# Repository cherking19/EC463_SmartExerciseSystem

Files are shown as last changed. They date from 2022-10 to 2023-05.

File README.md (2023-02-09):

# SeniorDesign_SmartExerciseSystem

Android:
Flutter compileSdkVersion, minSdkVersion, and targetSdkVersion changed to 33

https://stackoverflow.com/questions/72697570/warning-the-plugin-permission-handler-android-requires-android-sdk-version-33
https://pub.dev/packages/flutter_local_notifications#gradle-setup

- All app changes will happen on the smart_gym folder.

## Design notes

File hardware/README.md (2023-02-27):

# Smart Gym Hardware

Circuit Diagram of Arduino Nano 33 BLE, and connected power control circuit and haptic motor controller.

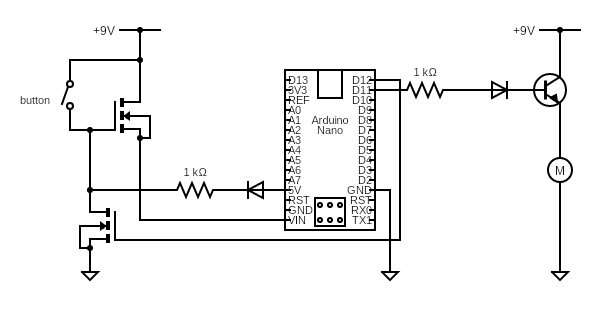
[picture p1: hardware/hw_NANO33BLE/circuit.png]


## Power Control Circuit

The power control circuit is designed to allow the user to power on the device with a single button press. The device will then remain powered on until the arduino sends an "off" signal (High/3.3V) from pin D12. This will cut off current from the connected Voltage Source (In this case, a 9V battery), and power off the arduino. 

The circuit is comprised of two NMOS transistors, a diode, and a resistor. The purpose of the first (top) transistor is to connect the positive terminal of the battery to the Vin pin. The transistor is opened by connecting the gate 9V, allowing the voltage source to pass to Vin. Once the arduino is powered on, the 5V output will turn on, and keep the first transistor open when the button is released. The diode prevents current from flowing back into the arduino when the button and 5V pins are both active. The second transistor will be off while the arduino is active, preventing any current flow from the 5V output, except for leakage. When the software determines that the arduino is inactive and will shut down, the second transistor is opened by setting D12 to HIGH. This pulls the gate of the first transistor to 0V, which turns off the transistor, and cuts off power to the arduino. Some current will pass through the resistor via the 5V pin very briefly.

This method powers on/off the device as soon as the button is pressed / the HIGh signal is sent to the second transistor.

## Haptic Motor
The Haptic Motor is controlled by a simple BJT transitor, modulated by pin D11, connected through a resistor and a diode to the BJT's gate. This allows current to flow from the 9V source through the motor when D11 is set to HIGH. In software, D11 can be set to HIGH for brief moments to activate the vibrate function. 

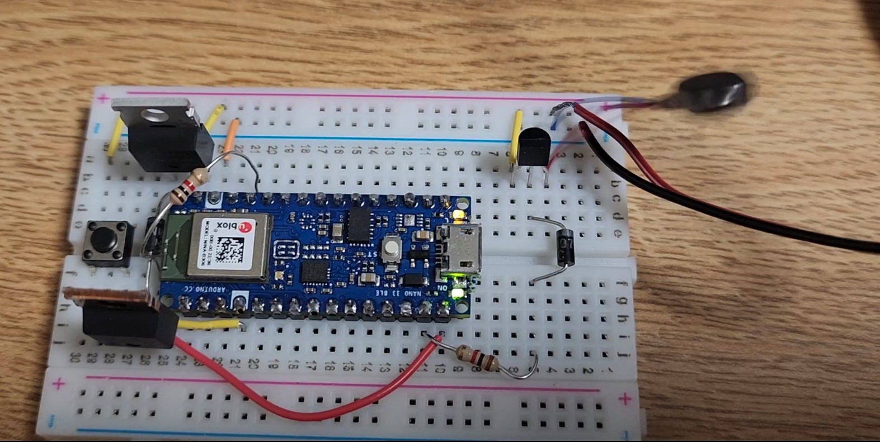
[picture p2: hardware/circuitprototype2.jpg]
prototype

(Prototype)

Arduino code:
In addition to library manager libraries: https://github.com/FemmeVerbeek/Arduino_LSM9DS1
library manager libraries: Adafruit_AHRS, ArduinoBLE

NOTE: In order to use the 5V pin, you must solder the VUSB pad

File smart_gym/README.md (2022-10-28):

# smart_gym

A new Flutter project.

## Getting Started

This project is a starting point for a Flutter application.

A few resources to get you started if this is your first Flutter project:

- [Lab: Write your first Flutter app](https://docs.flutter.dev/get-started/codelab)
- [Cookbook: Useful Flutter samples](https://docs.flutter.dev/cookbook)

For help getting started with Flutter development, view the
[online documentation](https://docs.flutter.dev/), which offers tutorials,
samples, guidance on mobile development, and a full API reference.

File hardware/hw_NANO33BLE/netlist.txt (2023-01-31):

* Netlist created with www.circuit-diagram.org
* seniordesignpower
D1 0 1
V2 2 0
'motor b:2 a:3 t=Generic
V3 4 9
'transnpn emit:1 base:3 col:4 t=NPN
R4 5 0 1000
V5 6 0
'toggleswitch a:7 t=Toggle closed=False
'Arduino Nano 28:5 18:6 14:8 29:9 11:10
'Arduino Nano
D6 10 11
V7 12 0
V8 7 9
R9 7 11 1000
'mosfetn gate:8 drn:7 t=NChannelMosfet
'mosfetn drn:7 gate:12 t=NChannelMosfet

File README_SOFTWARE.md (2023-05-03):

## Software

### Modules

The UI consists of pages for creating, managing, and tracking workout routines. The main page is made up of 3 tabs: Workout, History, and Settings.

#### Workout

The Workout tab is where the user creates routines and tracks workouts. In the paradigm of the app, a routine/workout contains the:

- Workout name
- A list of exercises that make up the workout

An exercise contains the:
- Exercise name
- A list of sets that make up the exercise
- Flags that indicate whether the sets share repetition, weight, and rest information

A set contains the: 
- Number of repetitions
- Weight 
- Rest duration

The Create Workout page consists of a form where the user enters information to create a routine. Upon the form initialization, a routine object is created to represent the workout. Each widget of the form corresponds to an element in the routine object according to the paradigm above. For example, modifications to an exercise widget will directly modify the values within the corresponding exercise. The form also validates the input to ensure each workout is named, contains at least one exercise, and has valid set information for each exercise. 

A user’s workout routines are saved in an unordered map for efficient retrieval. Each routine has an associated UUID to act as the key. This UUID is not visible to the user but allows multiple routines of the same name. 

The View Workouts page will display all the routines that the user has created. Upon initialization, this map is loaded and a list item generated from each entry. Clicking on one will display that routine’s information. Here, the user can edit the routine in a manner similar to the workout creation or delete the routine entirely. They can also begin tracking the workout, which will open the Track Workout page. 

When the workout is beginning to be tracked, its information is passed to the Track Workout service. This ensures that the information is both accessible throughout the app and also persists even when the Track Workout page is no longer displayed. These functionalities are required because the user will interact with the tracked workout in two ways: primarily through the Track Workout page where the complete workout progress is displayed and recorded but also through the Rest Timer widget which appears at the bottom of the Workout Page to indicate the current rest time. Multiple timer services are also running in the background to keep track of the rest duration and elapsed workout duration. 
Within the Track Workout page, the user will execute the workout. The user can either manually or automatically track each set of an exercise. In manual tracking, the user will perform the set without the analysis of the sensors and record how many successful repetitions they completed by tapping on the rep counter. 

The automatic tracking interfaces with the sensor service which provides the most up to date sensor measurements. These measurements are organized in a map, where the key is the name of the sensor node corresponding to the position on the body, and the value is the most recent measurement at that node. Each time new measurements are received, the service will update the map and broadcast an event. The track workout service contains a listener that will listen for these events and will subsequently run an iteration of the exercise analysis. By examining the change in sensor measurements from one iteration to the next, the analysis can determine whether a rep has been successfully completed, and report to the UI to reflect progress.

#### History

The History module displays the results of recorded workouts in both a List and Calendar view. Clicking on a record will enter the View Completed Workout page, where the user can view their results for that workout. While a workout object can represent a template of a routine, it can also represent a completed workout’s results. There are additional nullable fields for maintaining the start date and time and workout duration. Set objects also contain an additional reps completed value. This allows progress to be directly recorded into the same template that is loaded into a Track Workout page and saved in the same format. As a result, the UI for viewing a completed workout can be very similar and functionality can be borrowed when making edits to a completed workout. The completed workouts are themselves saved in a manner very similar to a user’s workout templates. 

#### Settings

Within the Settings module, the user can edit their profile and connect to the Smart Gym sensors. The Bluetooth settings page will display all the Smart Gym sensors in range that are connectable, as well as those that are already connected. This system makes use of the FlutterBlue plugin which takes care of many of the lower level Bluetooth system calls to enable cross platform Bluetooth functionality. Upon opening the Bluetooth settings page, the app periodically listens for newly connected and scanned Bluetooth devices. These results are filtered so that only devices with a preset device name prefix are displayed, ensuring that within the app the user can only interact with Smart Gym sensors. When a device is connected, the app begins listening to the orientation service as named in the Arduino code, and continuously retrieves the measurement data. This data is then passed to the previously mentioned sensor service and made available to the entirety of the app. 

### Software Flowchart

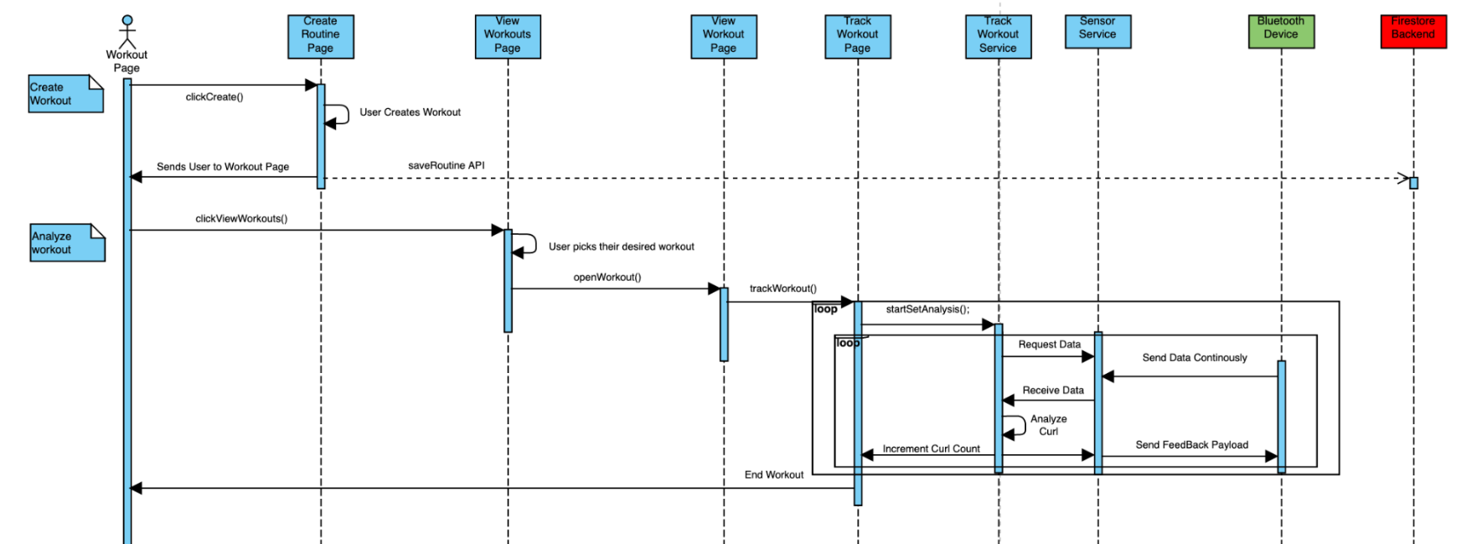
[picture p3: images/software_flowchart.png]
Flowchart


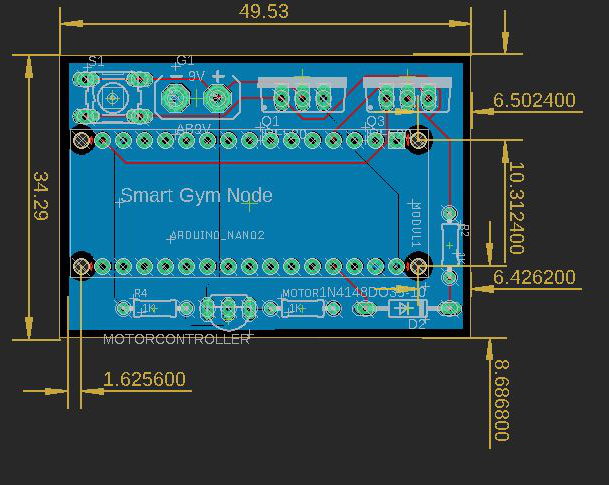
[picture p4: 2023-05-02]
hardware/pcb.jpg

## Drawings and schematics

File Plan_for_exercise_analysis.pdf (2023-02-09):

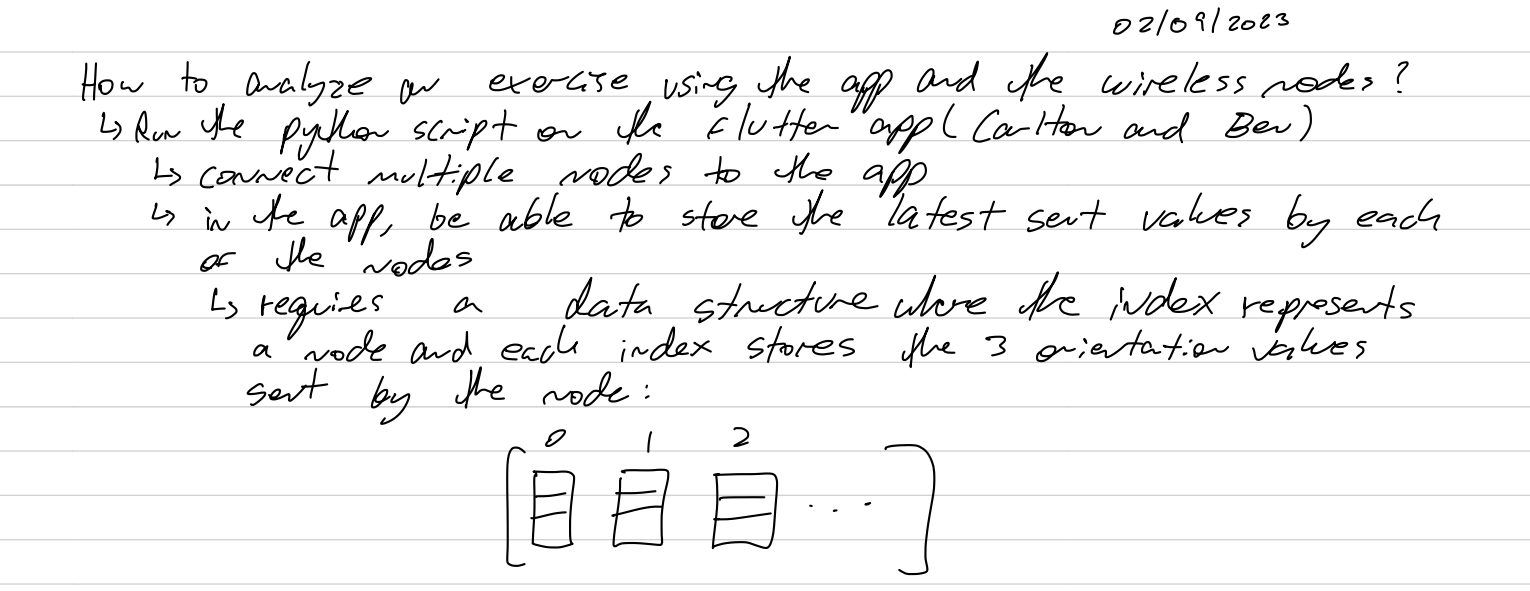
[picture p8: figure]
↳ correctmultiple rodes totheapp; ofthe rodes; setby the mode: LEEE...]

How to analyze or | exercise | using theapp and the wireless modes?
↳ Row thepython scriptor the flutter apple Coulton and Berl
2 | in theapp, be able tostorethelatestsentvalues by each
↳s requires | data structure where the index represents a | rode andeach index stores | the orientation values
Pebate between Coulter and Bor abouthow we | should approach
Ber: we | should label each ofthe rodes and tell the uses which

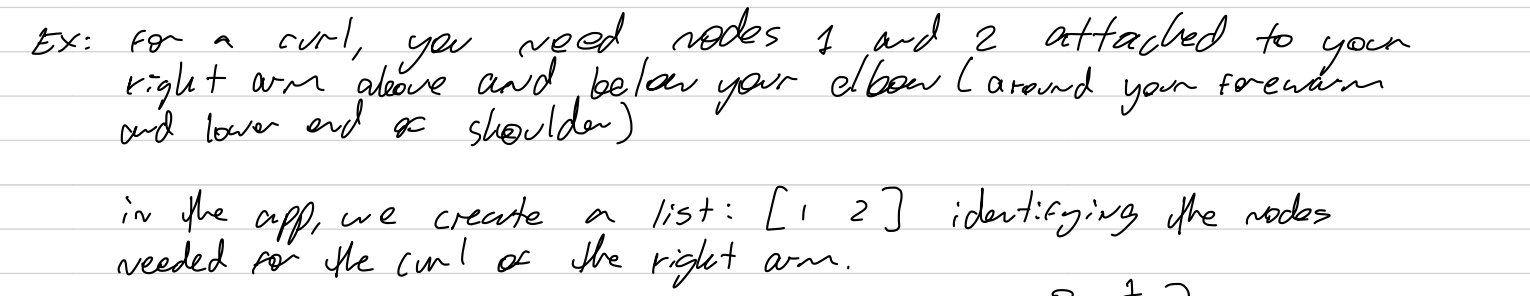
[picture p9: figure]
forewarm; and lower and ofshoulder); in theapp, we; createa list:[12] identifying the rodes; needed to the curl oftherightarm.

Ex.for | a | surl, you need nodes 1 | and I | attached toyour rightare above and below your allow (around your

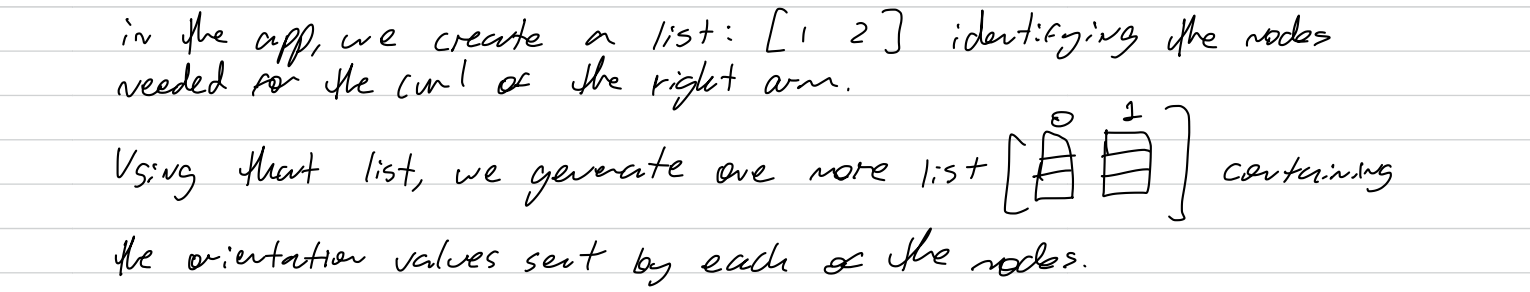
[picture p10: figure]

Using thatlist, we | generate aremore | listcertaining

the orientation values sentby each ofthemodes.

Then, we | send thisfinal listto thescriptfor theanalysis ofthe
Carlton:We | should have all the rodes as genetic and the app assigns
a | label toeach of the rodes dynamically. Theuse knows

to your rightforearm. Now, attach vileating rode (the Nextore) tothe

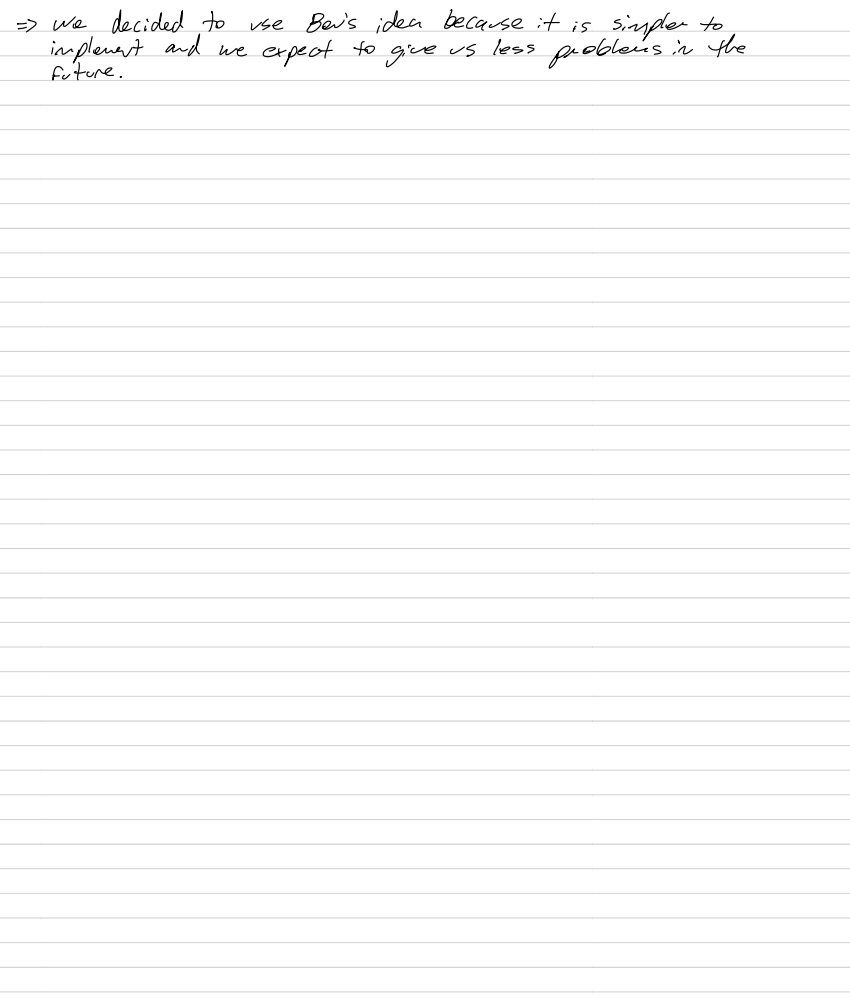
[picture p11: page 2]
decided to; use; Bar's idea because itis simpler to; implementand we; expecttogive as; less problems in the; future.

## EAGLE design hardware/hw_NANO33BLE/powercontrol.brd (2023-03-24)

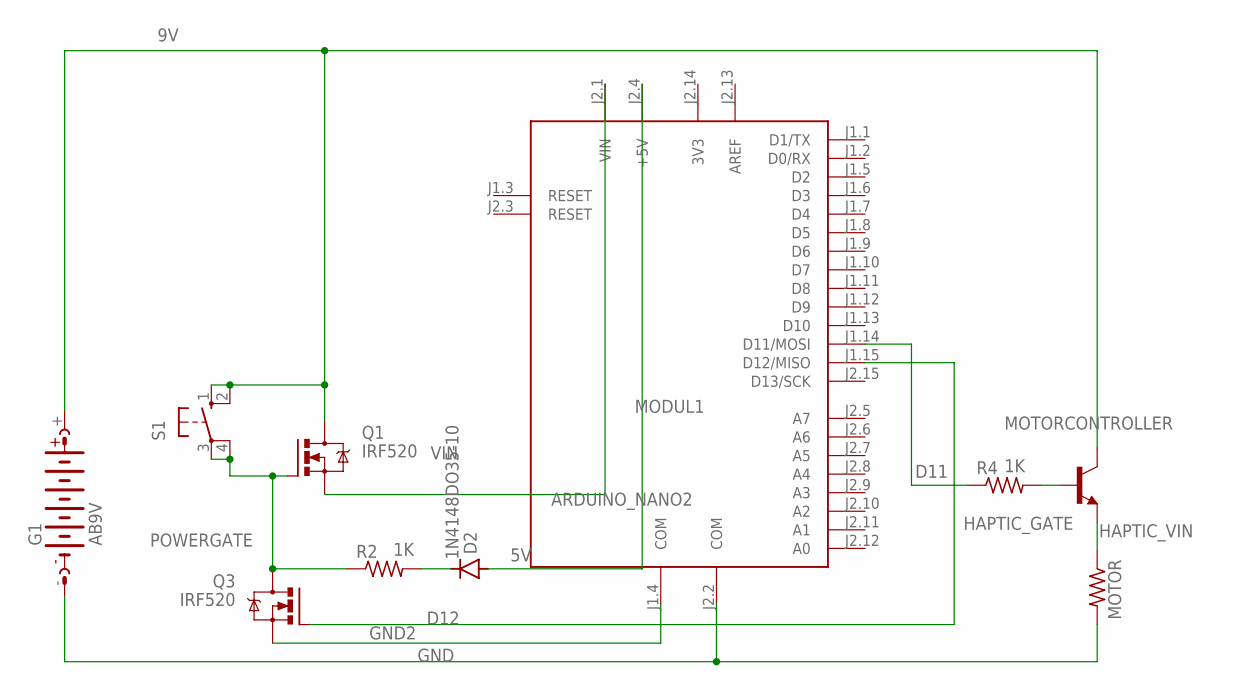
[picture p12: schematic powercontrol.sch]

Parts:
D2: 1N4148DO35-10; DO35-10
G1: AB9V
MODUL1: ARDUINO_NANO2
MOTOR: 1K; 0204/7
MOTORCONTROLLER: 2N2222-NPN-TO92-EBC; TO92-EBC
Q1, Q3: IRF520; TO220BV
R2, R4: 1K; 0204/7
S1: 10-XX; B3F-10XX

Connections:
3V3: MODUL1.J2.14 (3V3)
5V: D2.A, MODUL1.J2.4 (+5V)
9V: G1.+, MOTORCONTROLLER.C, Q1.D, S1.1 (S), S1.2 (S1)
AREF: MODUL1.J2.13 (AREF)
D11: MODUL1.J1.14 (D11/MOSI), R4.1
D12: MODUL1.J1.15 (D12/MISO), Q3.G
DIODE_TO_RESISTOR: D2.C, R2.2
GND: G1.-, MODUL1.J2.2 (COM), MOTOR.2
GND2: MODUL1.J1.4 (COM), Q3.S
HAPTIC_GATE: MOTORCONTROLLER.B, R4.2
HAPTIC_VIN: MOTOR.1, MOTORCONTROLLER.E
POWERGATE: Q1.G, Q3.D, R2.1, S1.3, S1.4 (P1)
VIN: MODUL1.J2.1 (VIN), Q1.S

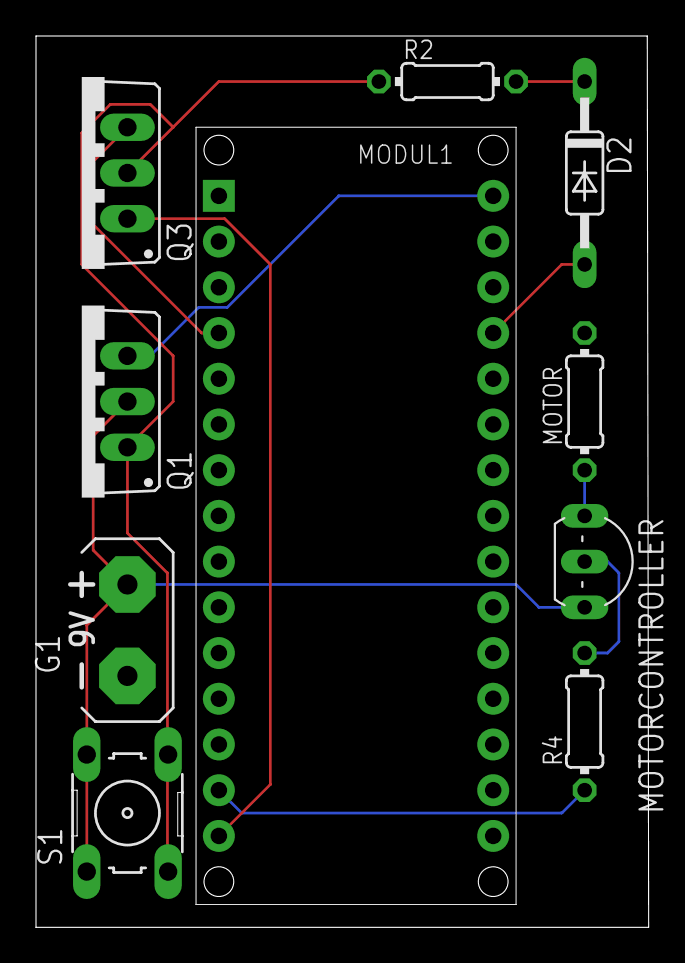
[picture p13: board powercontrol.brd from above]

Board: 2 copper layers, 34.0 x 49.5 mm, 10 parts (0 on the bottom side), 11 nets.

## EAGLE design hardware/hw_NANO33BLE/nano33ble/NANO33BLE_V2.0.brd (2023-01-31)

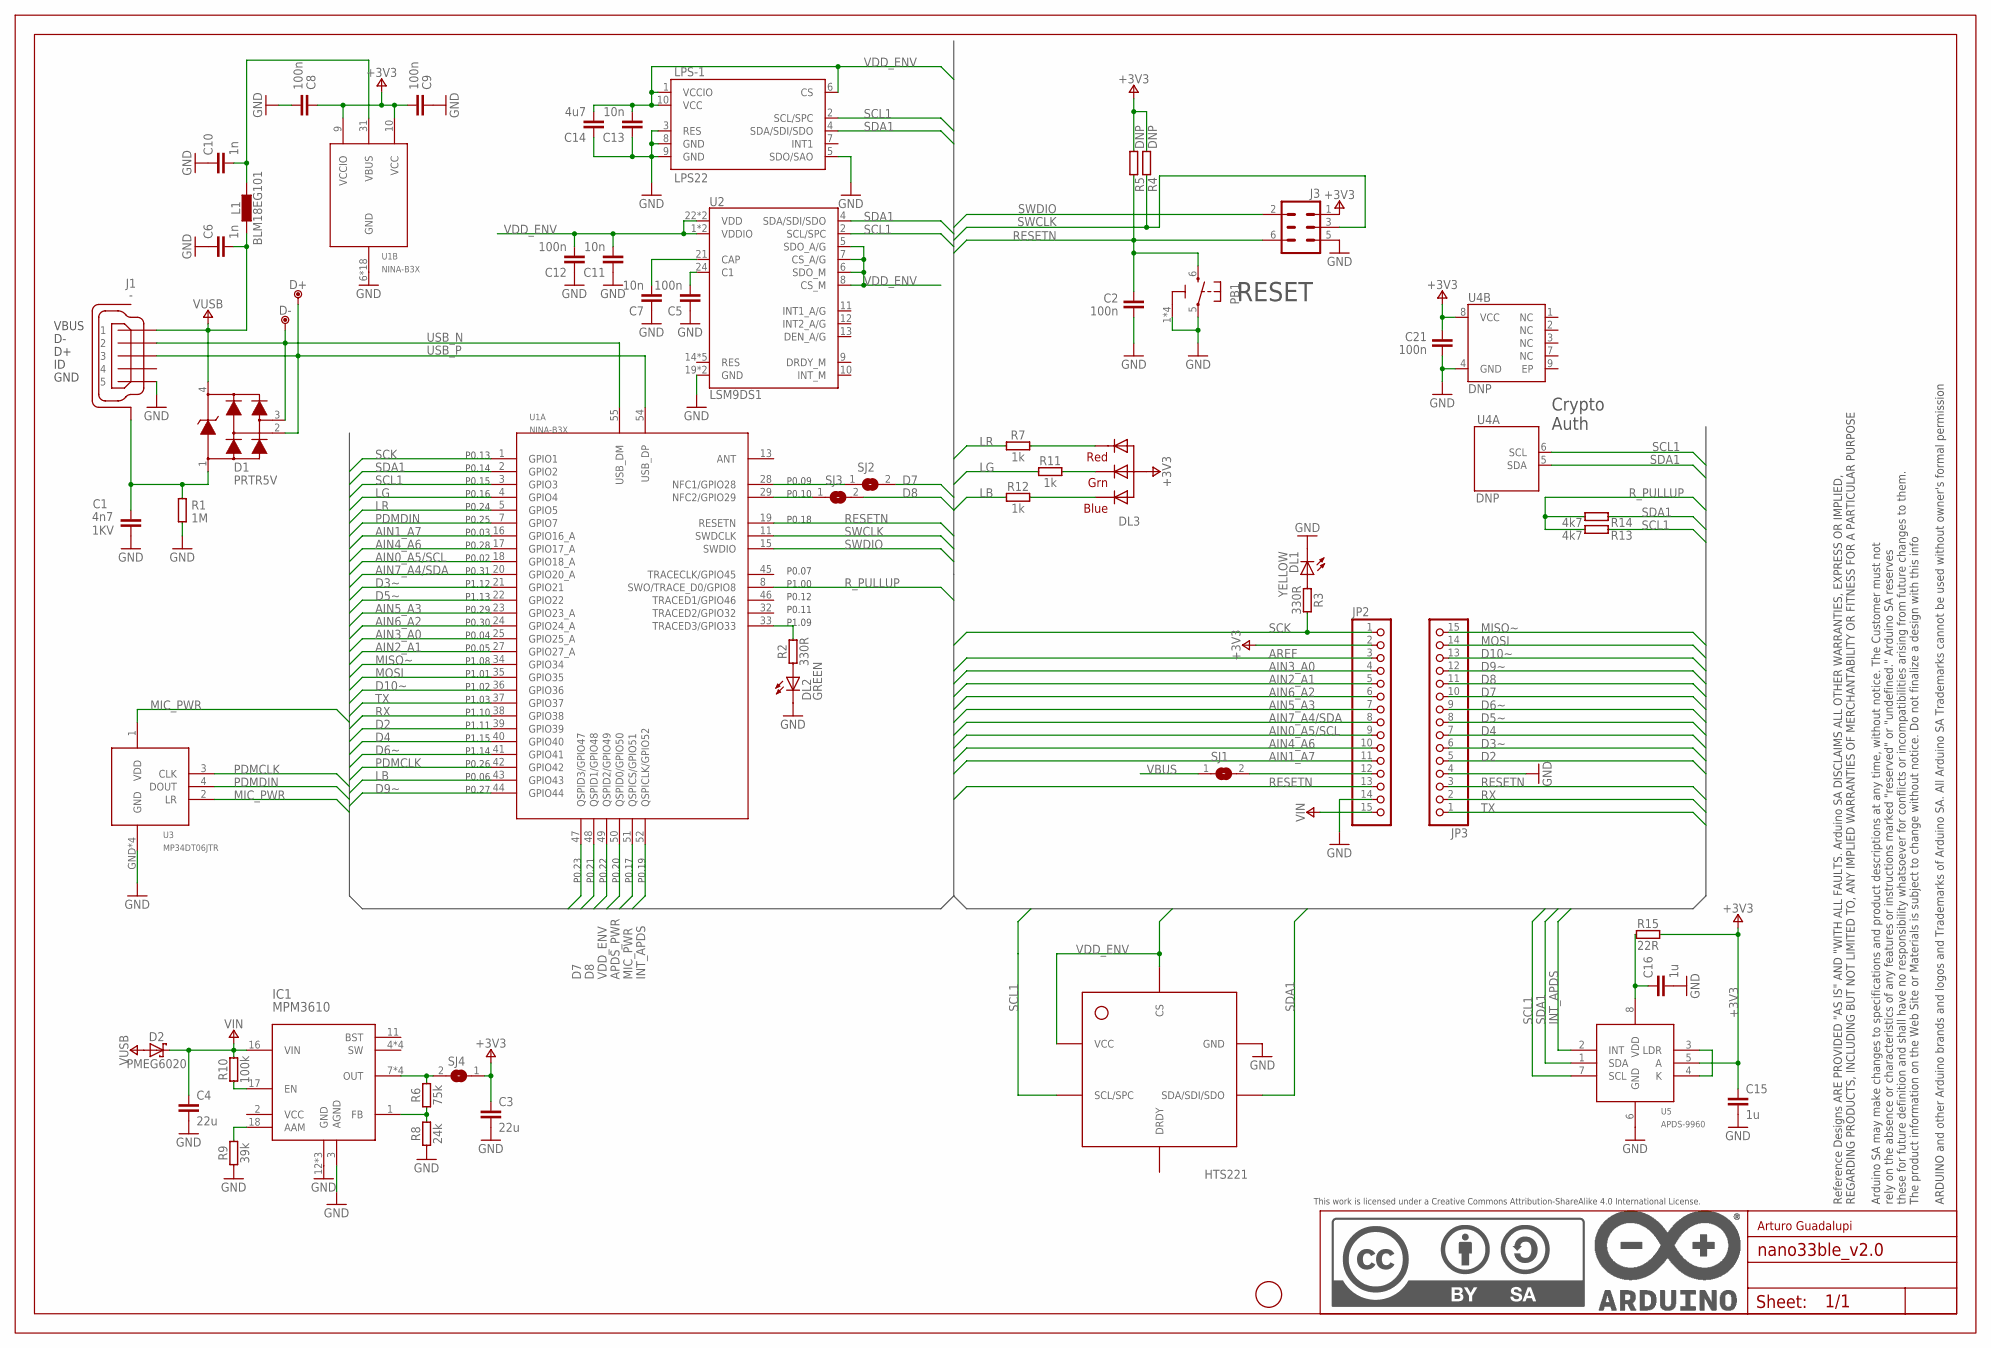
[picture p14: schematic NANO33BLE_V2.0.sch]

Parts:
C1: 4n7; 0805-R2013X50N; VOLTAGE 1KV
C2, C5, C8, C9, C12, C21: 100n; 0402-1005X55N
C3, C4: 22u; 0805-R2013X50N
C6, C10: 1n; 0402-1005X55N
C7, C11, C13: 10n; 0402-1005X55N
C14: 4u7; 0402-1005X55N
C15, C16: 1u; 0402-1005X55N
D1: PRTR5V; SOT190P230X110-4N
D2: PMEG6020; SODFL3517X110N
D+: DNP; TP-1.00MM
D-: DNP; TP-1.00MM
DL1: YELLOW; LEDC1608X80N-AK
DL2: GREEN; LEDC1608X80N-AK
DL3: -; SMLP34RGB2W
FD1: DNP; FD-1-1.5
FRAME1: DNP; FRAME
HS-1: HTS221
IC1: MPM3610
J1: -; ZX62-AB-5PA
J3: DNP; 2X03-TP1
JP2, JP3: PINHD-1X15-CASTELLATED; 1X15-CASTELL
L1: BLM18EG101; 0603-1608X90N
LPS-1: LPS22; LPS22H
PB1: PTS820; C&K_PTS820_NO_HOLES
R1: 1M; 0402-1005X55N
R2, R3: 330R; 0402-1005X55N
R4, R5: DNP; 0402-1005X55N
R6: 75k; 0402-1005X55N
R7, R11, R12: 1k; 0402-1005X55N
R8: 24k; 0402-1005X55N
R9: 39k; 0402-1005X55N
R10: 100k; 0402-1005X55N
R13, R14: 4k7; 0402-1005X55N
R15: 22R; 0402-1005X55N
SJ1, SJ2, SJ3, SJ4: DNP; SJ
U1: NINA-B3X
U2: LSM9DS1; LSM9DS1_TEMP_LGA24-8X4
U3: MP34DT06JTR; HCLGA
U4: DNP; SON50P300X200X60-9N-EP160X140
U5: APDS-9960; APDS9960

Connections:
+3V3: C3.1, C8.1, C9.2, C15.1, C21.1, DL3.1 (A), J3.1, JP2.2, R4.2, R5.2, R15.2, SJ4.1, U1.9 (VCCIO), U1.10 (VCC), U4.8 (VCC), U5.5 (A)
AIN0_A5/SCL: JP2.9, U1.18 (GPIO18_A)
AIN1_A7: JP2.11, U1.16 (GPIO16_A)
AIN2_A1: JP2.5, U1.27 (GPIO27_A)
AIN3_A0: JP2.4, U1.25 (GPIO25_A)
AIN4_A6: JP2.10, U1.17 (GPIO17_A)
AIN5_A3: JP2.7, U1.23 (GPIO23_A)
AIN6_A2: JP2.6, U1.24 (GPIO24_A)
AIN7_A4/SDA: JP2.8, U1.20 (GPIO20_A)
APDS_PWR: U1.50 (QSPID0/GPIO50)
AREF: JP2.3
D2: JP3.5, U1.39 (GPIO39)
D3~: JP3.6, U1.21 (GPIO21)
D4: JP3.7, U1.40 (GPIO40)
D5~: JP3.8, U1.22 (GPIO22)
D6~: JP3.9, U1.41 (GPIO41)
D7: JP3.10, SJ2.2, U1.47 (QSPID3/GPIO47)
D8: JP3.11, SJ3.2, U1.48 (QSPID1/GPIO48)
D9~: JP3.12, U1.44 (GPIO44)
D10~: JP3.13, U1.36 (GPIO36)
GND: C1.2, C2.2, C3.2, C4.2, C5.1, C6.1, C7.1, C8.2, C9.1, C10.1, C11.1, C12.1, C13.1, C14.1, C15.2, C16.2, C21.2, DL1.C, DL2.C, HS-1.P$5.GND (GND), IC1.3 (AGND), IC1.12 (GND), IC1.13 (GND), IC1.14 (GND), J1.5, J3.5, JP2.14, JP3.4, LPS-1.3 (RES), LPS-1.5 (SDO/SAO), LPS-1.8 (GND), LPS-1.9 (GND), PB1.1 (3), PB1.2 (3), PB1.3, PB1.4 (3), PB1.5 (1), R1.1, R8.1, R9.1, U1.6 (GND), U1.12 (GND), U1.14 (GND), U1.26 (GND), U1.30 (GND), U1.53 (GND), U1.GND@1 (GND), U1.GND@2 (GND), U1.GND@3 (GND), U1.GND@4 (GND), U1.GND@5 (GND), U1.GND@6 (GND), U1.GND@7 (GND), U1.GND@8 (GND), U1.GND@9 (GND), U1.GND@10 (GND), U1.GND@11 (GND), U1.GND@12 (GND), U2.19 (GND), U2.20 (GND), U3.GND, U3.GND@2 (GND), U3.GND@3 (GND), U3.GND@4 (GND), U4.4 (GND), U5.6 (GND)
INT_APDS: U1.52 (QSPICLK/GPIO52), U5.2 (INT)
LB: R12.1, U1.43 (GPIO43)
LG: R11.1, U1.4 (GPIO4)
LR: R7.1, U1.5 (GPIO5)
MIC_PWR: U1.51 (QSPICS/GPIO51), U3.1 (VDD), U3.2 (LR)
MISO~: JP3.15, U1.34 (GPIO34)
MOSI: JP3.14, U1.35 (GPIO35)
unnamed: C1.1, D1.1, J1.6 (SH), J1.7 (SH), J1.8 (SH), J1.9 (SH), J1.10 (SH), J1.11 (SH), R1.2
unnamed: DL2.A, R2.1
unnamed: DL1.A, R3.1
unnamed: C5.2, U2.24 (C1)
unnamed: IC1.1 (FB), R6.1, R8.2
unnamed: IC1.18 (AAM), R9.2
unnamed: IC1.17 (EN), R10.1
unnamed: C7.2, U2.21 (CAP)
unnamed: U5.3 (LDR), U5.4 (K)
unnamed: R2.2, U1.33 (TRACED3/GPIO33)
unnamed: DL3.3 (BLUE_C), R12.2
unnamed: DL3.2 (RED_C), R7.2
unnamed: DL3.4 (GREEN_C), R11.2
unnamed: JP2.12, SJ1.2
unnamed: C16.1, R15.1, U5.8 (VDD)
unnamed: IC1.7 (OUT), IC1.8 (OUT), IC1.9 (OUT), IC1.20 (OUT), R6.2, SJ4.2
NFC1: SJ2.1, U1.28 (NFC1/GPIO28)
NFC2: SJ3.1, U1.29 (NFC2/GPIO29)
PDMCLK: U1.42 (GPIO42), U3.3 (CLK)
PDMDIN: U1.7 (GPIO7), U3.4 (DOUT)
RESETN: C2.1, J3.6, JP2.13, JP3.3, PB1.6 (2), R5.1, U1.19 (RESETN)
RX: JP3.2, U1.38 (GPIO38)
R_PULLUP: R13.2, R14.2, U1.8 (SWO/TRACE_D0/GPIO8)
SCK: JP2.1, R3.2, U1.1 (GPIO1)
SCL1: HS-1.P$2.SCL/SPC (SCL/SPC), LPS-1.2 (SCL/SPC), R13.1, U1.3 (GPIO3), U2.2 (SCL/SPC), U4.6 (SCL), U5.7 (SCL)
SDA1: HS-1.P$4.SDA/SDI/SDO (SDA/SDI/SDO), LPS-1.4 (SDA/SDI/SDO), R14.1, U1.2 (GPIO2), U2.4 (SDA/SDI/SDO), U4.5 (SDA), U5.1 (SDA)
SWCLK: J3.3, R4.1, U1.11 (SWDCLK)
SWDIO: J3.2, U1.15 (SWDIO)
TX: JP3.1, U1.37 (GPIO37)
USB_N: D1.3, D-.X, J1.2, U1.55 (USB_DM)
USB_P: D1.2, D+.X, J1.3, U1.54 (USB_DP)
VBUS: C10.2, L1.2, SJ1.1, U1.31 (VBUS)
VDD_ENV: C11.2, C12.2, C13.2, C14.2, HS-1.P$1.VDD (VCC), HS-1.P$6.CS (CS), LPS-1.1 (VCCIO), LPS-1.6 (CS), LPS-1.10 (VCC), U1.49 (QSPID2/GPIO49), U2.1 (VDDIO), U2.3 (VDDIO), U2.5 (SDO_A/G), U2.6 (SDO_M), U2.7 (CS_A/G), U2.8 (CS_M), U2.22 (VDD), U2.23 (VDD)
VIN: C4.1, D2.C, IC1.16 (VIN), JP2.15, R10.2
VUSB: C6.2, D1.4, D2.A, J1.1, L1.1

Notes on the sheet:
RESET
Crypto Auth
Arturo Guadalupi
HTS221

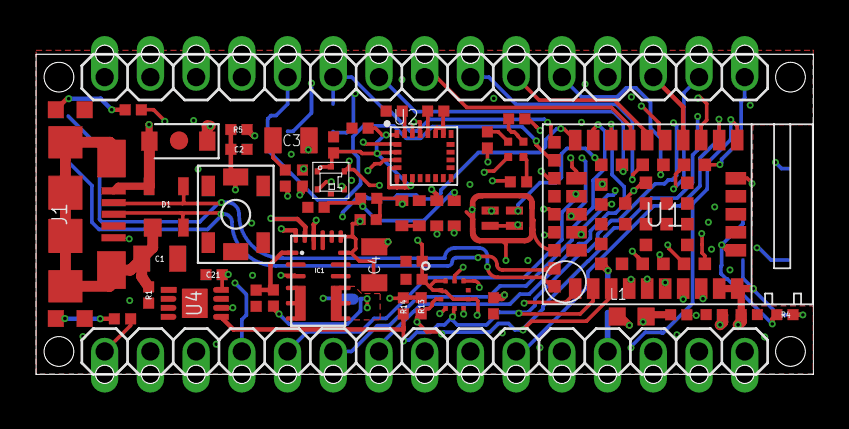
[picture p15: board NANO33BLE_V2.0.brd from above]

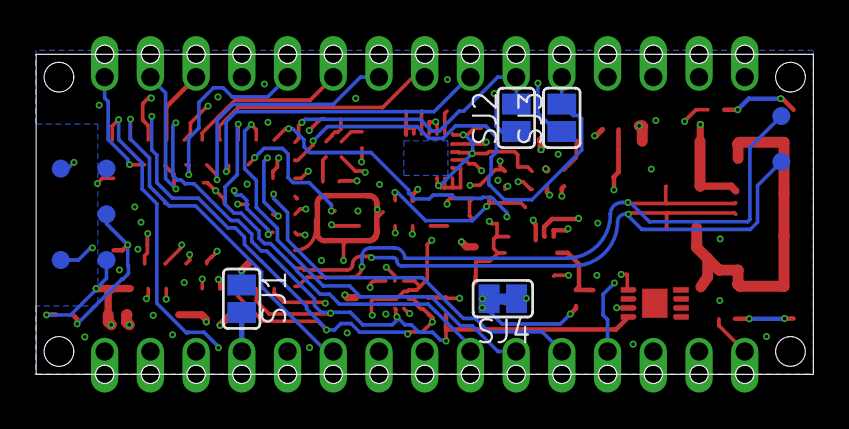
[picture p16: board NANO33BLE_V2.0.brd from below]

Board: 4 copper layers, 43.2 x 17.8 mm, 59 parts (4 on the bottom side), 61 nets.

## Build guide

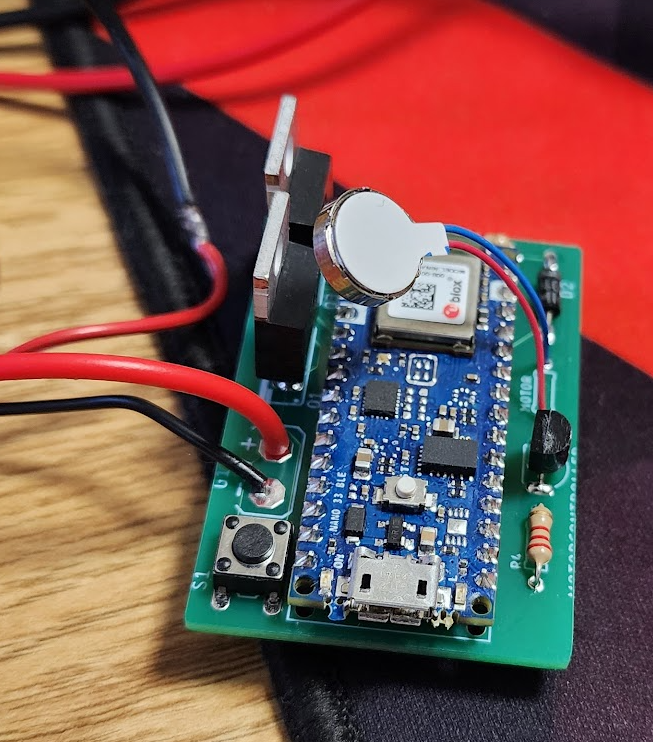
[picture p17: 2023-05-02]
hardware/pcb_assembled.png

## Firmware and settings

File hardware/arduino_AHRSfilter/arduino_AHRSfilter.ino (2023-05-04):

#include <Arduino_LSM9DS1.h>
#include <Adafruit_AHRS.h>
#include <ArduinoBLE.h>
#define sensorRate 104.00
Adafruit_Mahony filter;

BLEService AHRSfilter("A123");                                              // create service
BLEFloatCharacteristic RollCharacteristic("2A19", BLERead | BLENotify);     //create Characteristic
BLEFloatCharacteristic PitchCharacteristic("2A20", BLERead | BLENotify);    //create Characteristic
BLEFloatCharacteristic HeadingCharacteristic("2A21", BLERead | BLENotify);  //create Characteristic

BLEService HapticFeedback("A124");
BLEByteCharacteristic switchCharacteristic("2A57", BLERead | BLEWrite);

//PINS
#define powerdrain 12
#define haptic 11

unsigned long start_time;
unsigned long last_connected_time;
unsigned long hapticTime;
char* deviceName = "SmartGymBros_RightForearm";
bool hapticState = false; // true means vibration is on

void setup() {
  Serial.begin(9600);
  pinMode(powerdrain, OUTPUT);
  pinMode(haptic, OUTPUT);
  digitalWrite(powerdrain, LOW);
  digitalWrite(haptic, LOW);

  // attempt to start the IMU:
  if (!IMU.begin()) {
    Serial.println("Failed to initialize IMU");
    // stop here if you can't access the IMU:
    while (true);
  }
  //Calibration: go to https://github.com/cherking19/EC463_SmartExerciseSystem/blob/main/hardware/arduino_calibrations to see appropriate values
  //Final PCB+bpx
// Accelerometer code
   IMU.setAccelFS(3);
   IMU.setAccelODR(5);
   IMU.setAccelOffset(0.014126, -0.035187, -0.000804);
   IMU.setAccelSlope (0.998022, 0.993426, 1.000934);
// Gyroscope code
   IMU.setGyroFS(2);
   IMU.setGyroODR(5);
   IMU.setGyroOffset (-0.420929, -0.346832, -0.530182);
   IMU.setGyroSlope (266.880188, 1.118256, 1.114424);
 // Magnetometer code
   IMU.setMagnetFS(0);
   IMU.setMagnetODR(8);
   IMU.setMagnetOffset(-5.938110, 13.554688, 39.260864);
   IMU.setMagnetSlope (1.868137, 1.904086, 2.080932);

   
  // start the filter to run at the sample rate:
  filter.begin(sensorRate);
  Serial.print("Orientation:\n");

  // BLE Setup  
  BLE.begin();
  BLE.setLocalName(deviceName);
  BLE.setAdvertisedService(AHRSfilter);
  AHRSfilter.addCharacteristic(RollCharacteristic);
  AHRSfilter.addCharacteristic(PitchCharacteristic);
  AHRSfilter.addCharacteristic(HeadingCharacteristic);
  BLE.addService(AHRSfilter);
  BLE.advertise();

// BLE.setAdvertisedService(HapticFeedback);
  HapticFeedback.addCharacteristic(switchCharacteristic);
  BLE.addService(HapticFeedback);
  // BLE.advertise();
  switchCharacteristic.setEventHandler(BLEWritten, switchCharacteristicWritten);
  
  //temporary counter
  start_time = millis();
  last_connected_time=start_time;
  // pinMode(LEDR, OUTPUT); // for testing with LEDR instead of haptic
  // digitalWrite(LEDR, HIGH);
}

void switchCharacteristicWritten(BLEDevice central, BLECharacteristic characteristic) {
  digitalWrite(haptic, HIGH);
  hapticTime = millis();
  hapticState = true;
  // if (hapticState) {
  //   digitalWrite(haptic, HIGH);
  //   //delay(1000); // the delay causes the lightBlue app to not connect with the Arduino
  //   hapticState = false;
  // } else {
  //   digitalWrite(haptic, LOW);
  //   hapticState = true;
  // }
}

void loop() {
  //power control---------------
  unsigned long nowtime = millis();
 
  //----------------------------
  // Turn off vibration after 200 milliseconds
  if (hapticState) {
    if (nowtime - hapticTime > 200) {
      digitalWrite(haptic, LOW);
    }
  }

  BLEDevice central = BLE.central();
  
  //Output Values
  float roll, pitch, heading;
  //IMU values
  float xAcc, yAcc, zAcc,
        xGyro, yGyro, zGyro,
        xMag, yMag, zMag;
  if(IMU.accelerationAvailable() && IMU.gyroscopeAvailable() && IMU.magneticFieldAvailable()) {
    IMU.readAcceleration(xAcc, yAcc, zAcc);
    IMU.readGyroscope(xGyro, yGyro, zGyro);
    IMU.readMagneticField(xMag, yMag, zMag);
  }
  //update filter
  filter.update(xGyro, yGyro, -zGyro, xAcc, yAcc, -zAcc, -xMag, yMag, -zMag);
  //get filter output:
  roll = filter.getRoll();
  pitch = filter.getPitch();
  heading = filter.getYaw();
  //print values
  Serial.print(deviceName);
  Serial.print("\theading: ");
  Serial.print(heading);
  Serial.print("\tpitch: ");
  Serial.print(pitch);
  Serial.print("\troll: ");
  Serial.println(roll);

  RollCharacteristic.writeValue(roll);
  PitchCharacteristic.writeValue(pitch);
  HeadingCharacteristic.writeValue(heading);
  if(BLE.connected()){
    Serial.println("CONNECtED");
    last_connected_time=nowtime;

  }
  else
    // Serial.println("NOT CONNECTED");
    if(nowtime-last_connected_time > 30000){
      Serial.println("NOT CONNECTED FOR 30 SECONDS. POWERING OFF");
      digitalWrite(powerdrain, HIGH);
    }
}

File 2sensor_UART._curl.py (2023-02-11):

import serial
import re
from timeit import default_timer as timer
from statistics import fmean
sensora = serial.Serial(port="COM13", baudrate=9600)
sensorb = serial.Serial(port="COM14", baudrate=9600)
sensors = [sensora,sensorb]
start=timer()
still=0
state=0
#states:
#0 = calibration
#1 = curling


prev_average = [[0,0,0],[0,0,0]]# 2 sensors, 3 previous average values (heading, pitch, roll)
data_average = [[0,0,0],[0,0,0]]# 2 sensors, 3 current average values (heading, pitch, roll)

data = [[[],[],[]],[[],[],[]]]# 2 sensors, 3 running lists per sensor (heading, pitch, roll)


import sys
debug = False  
if(len(sys.argv)>1):
    debug=sys.argv[1]

print("Please hold still in rest position for (3) seconds.")

while(True):
    for sensor in sensors: # if data, read it
        if sensor.in_waiting > 0:
            
            # Read data from buffer until return/newline found
            serialString = sensor.readline()
            # print(serialString.decode("Ascii").strip().split('\t'))
            try:
                input = serialString.decode("Ascii")
                node,heading_str,pitch_str,roll_str = input.strip().split('\t')
                heading = float(heading_str[9:])# "heading: xxxx.xxxx"
                pitch = float(pitch_str[7:])    # "pitch: xxxx.xxxx"
                roll = float(roll_str[6:])      # "roll: xxxx.xxxx"
                if(node=="Node1"):
                    i_n=0
                elif(node=="Node2"):
                    i_n=1
                else:
                    raise SystemExit("not valid node name")
            
                if(debug):
                    print("NODE",i_n+1,heading,pitch,roll)
            
                data[i_n][0].append(heading)
                data[i_n][1].append(pitch)
                data[i_n][2].append(roll)
                
                
            except:
                pass
            
            
    now=timer()
    if((now-start)>.1):
        # print(".1 second has passed")
        start=timer()
        
        try: 
            tmp_data_average = [[fmean(data[i_n][s_v]) for s_v in range(3)] for i_n in range(len(sensors))]
        except:
            print("no data")
            continue
        
        prev_average = data_average
              
        data_average = tmp_data_average
        
        if(state==0):# calibration state
            if(debug):
                print(abs(data_average[0][0]-data_average[1][0]), abs(data_average[0][2]-data_average[1][2]),abs(data_average[0][1]-data_average[1][1]))
            # if(abs(data_average[0][0]-prev_average[0][0])<1 and abs(data_average[0][2]-prev_average[0][2])<1 and abs(data_average[0][1]-prev_average[0][1])<1):
            #     still=still+1
            # else:
            #     still=0
            # if(still>=30):
            #     start_y,start_p,start_r = data_average[0][0],data_average[0][1],data_average[0][2]
            #     print("calibration complete, starting point = ",data_average[0][0],data_average[0][1],data_average[0][2])
            #     state=1
            #     curls=0
            #     still=0
            still=30
            # if(abs(data_average[0][0]-data_average[1][0])<10 and abs(data_average[0][2]-data_average[1][2])<10 and abs(data_average[0][1]-data_average[1][1])<10):
            #     still=still+1
            # else:
            #     still=0
            
            if(still>=30):
                # start_y,start_p,start_r = data_average[0][0],data_average[0][1],data_average[0][2]
                print("calibration complete")
                state=1
                curls=0
                still=0
        elif(state==1):# after calibration, down state
            dy,dp,dr=abs(data_average[0][0]-data_average[1][0]),abs(data_average[0][1]-data_average[1][1]),abs(data_average[0][2]-data_average[1][2])
            
            if(debug):
                print(dy,dp,dr)
                
            if(dp>60):
                state=2 #up state
                holdup=0
            # else: 
                # if(abs(data_average[0][0]-prev_average[0][0])<1 and abs(data_average[0][2]-prev_average[0][2])<1 and abs(data_average[0][1]-prev_average[0][1])<1 and abs(data_average[0][1])<5):
                #     still=still+1
                # else:
                #     still=0
                # if(still>=30):
                #     start_y,start_p,start_r = data_average[0][0],data_average[0][1],data_average[0][2]
                #     if(debug):
                #         print("calibration complete, starting point = ",data_average[0][0],data_average[0][1],data_average[0][2])
                #     still=0
        elif(state==2):
            dy,dp,dr=abs(data_average[0][0]-data_average[1][0]),abs(data_average[0][1]-data_average[1][1]),abs(data_average[0][2]-data_average[1][2])
            holdup=holdup+1
            if(debug):
                print(dy,dp,dr)
            if(dp<15): #go to finish state
                state=3
        elif(state==3):# finish rep state
            curls=curls+1
            print("curl number",curls,"held for",holdup/10,"seconds")
            state=1 # go back to down state for next rep
                
        # reset collection of values used to calculate average  over .1 seconds
        data[0][0]=[]
        data[0][1]=[]
        data[0][2]=[]
    # else:
            

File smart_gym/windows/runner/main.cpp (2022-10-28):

#include <flutter/dart_project.h>
#include <flutter/flutter_view_controller.h>
#include <windows.h>

#include "flutter_window.h"
#include "utils.h"

int APIENTRY wWinMain(_In_ HINSTANCE instance, _In_opt_ HINSTANCE prev,
                      _In_ wchar_t *command_line, _In_ int show_command) {
  // Attach to console when present (e.g., 'flutter run') or create a
  // new console when running with a debugger.
  if (!::AttachConsole(ATTACH_PARENT_PROCESS) && ::IsDebuggerPresent()) {
    CreateAndAttachConsole();
  }

  // Initialize COM, so that it is available for use in the library and/or
  // plugins.
  ::CoInitializeEx(nullptr, COINIT_APARTMENTTHREADED);

  flutter::DartProject project(L"data");

  std::vector<std::string> command_line_arguments =
      GetCommandLineArguments();

  project.set_dart_entrypoint_arguments(std::move(command_line_arguments));

  FlutterWindow window(project);
  Win32Window::Point origin(10, 10);
  Win32Window::Size size(1280, 720);
  if (!window.CreateAndShow(L"smart_gym", origin, size)) {
    return EXIT_FAILURE;
  }
  window.SetQuitOnClose(true);

  ::MSG msg;
  while (::GetMessage(&msg, nullptr, 0, 0)) {
    ::TranslateMessage(&msg);
    ::DispatchMessage(&msg);
  }

  ::CoUninitialize();
  return EXIT_SUCCESS;
}

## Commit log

2022-12-05 arduino example code to auto calibrate absolute orientation
2022-12-05 working serial curl demo 1 sensor
2022-12-05 catch back case
2022-12-05 Fixed back button and added addworkout cloud function
2022-12-05 added printout
2022-12-13 Start timer
2022-12-13 Global Timer
2023-01-13 power controller arduino code and eagle cad schematic
    [NANO33BLE_V2.0.brd, NANO33BLE_V2.0.sch, powercontrol.sch]
2023-01-13 added code to control haptic motor, and circuit image
2023-01-16 updated circuit to add another diode
2023-01-16 updated ARHS filter to include magnetometer
    [NANO33BLE_V2.0.brd, NANO33BLE_V2.0.sch, powercontrol.sch]
2023-01-17 switched from lsm9ds1 library 1.0 to 2.0. added calibration code
2023-01-17 merged arduino files into one
2023-01-22 updated circuit
2023-02-09 Set up track workout page to be used to display sensors
2023-02-10 setup continuous sensor reading widgets (not tested)
2023-02-12 Setup sensor provider
2023-02-17 Fix bug with multiple streams listened to and iOS device name
2023-02-23 Create arduino_calibrations
2023-03-23 pcb in progress
    [NANO33BLE_V2.0.brd, NANO33BLE_V2.0.sch, powercontrol.brd]
2023-03-24 finished pcb
    [powercontrol.brd, powercontrol.sch]
2023-03-24 added pcb gerber
2023-03-28 arduino code
2023-03-28 battery timeout
2023-04-18 fixed arduino codes
2023-05-03 add software flowchart images folder

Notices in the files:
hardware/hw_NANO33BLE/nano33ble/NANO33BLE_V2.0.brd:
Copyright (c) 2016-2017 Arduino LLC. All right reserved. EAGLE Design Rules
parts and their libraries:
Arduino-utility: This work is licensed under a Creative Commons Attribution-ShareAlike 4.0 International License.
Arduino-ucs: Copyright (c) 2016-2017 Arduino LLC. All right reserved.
